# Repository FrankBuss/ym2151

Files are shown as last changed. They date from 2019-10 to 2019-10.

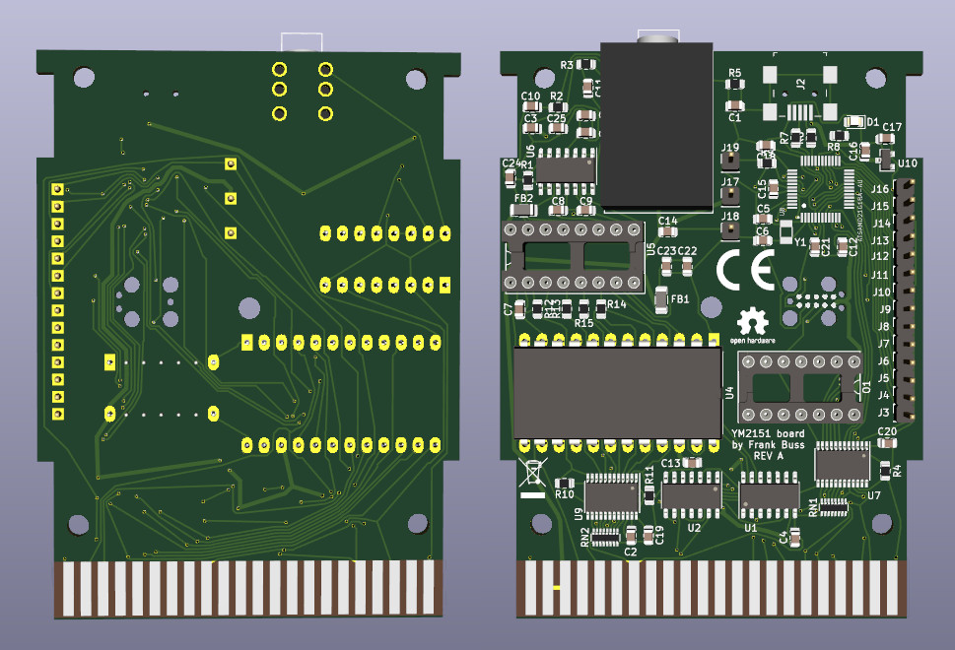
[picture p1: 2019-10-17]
KiCAD/board.jpg

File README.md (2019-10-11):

# YM2151 board for C64 and Arduino

## Original Z80 project
https://github.com/kuninet/Z80_YM2151

## C64 Sound Expander circuit diagram
https://www.c64-wiki.de/images/0/0f/Commodore_Sound_Expander_Schematic_SVG.svg

## Parts
TRS connector: https://www.tme.eu/en/details/acjs-nh35/jack-connectors/amphenol/

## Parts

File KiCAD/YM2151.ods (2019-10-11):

部品番号 | 仕様 | 数量 | 代替可能品 | Footprint
P1 | 1列x8 ピンヘッダ等 | 1 |  | Socket_Arduino_Uno:Socket_Strip_Arduino_1x08
P2 | 1列x6 ピンヘッダ等 | 1 |  | Socket_Arduino_Uno:Socket_Strip_Arduino_1x06
P4 | 1列x8 ピンヘッダ等 | 1 |  | Socket_Arduino_Uno:Socket_Strip_Arduino_1x08
P3 | 1列x10 ピンヘッダ等 | 1 |  | Socket_Arduino_Uno:Socket_Strip_Arduino_1x10
U1 | YM2151 | 1 | - | Housings_DIP:DIP-24_W15.24mm_Socket
U2 | YM3012 | 1 | - | Housings_DIP:DIP-16_W7.62mm_Socket
U3 | LMC6484 | 1 | LMC660CN等 4回路入 単一電源オペアンプ | Housings_DIP:DIP-14_W7.62mm_Socket
U4 | 74HC138 | 1 | 74HCT138 | Package_DIP:DIP-16_W7.62mm_Socket
C1 | 10uF | 1 | 電解コンデンサ | Capacitor_THT:CP_Radial_D5.0mm_P2.50mm
C2、C3 | 3300p | 2 | フィルム or 積層セラミックコンデンサ | Capacitor_THT:C_Disc_D4.3mm_W1.9mm_P5.00mm
C4、C5、C6、C10、C11 | 4.7u | 5 | 電解コンデンサ | Capacitor_THT:CP_Radial_D5.0mm_P2.50mm
C7、C8、C9 | 0.1u | 3 | 積層セラミックコンデンサ | Capacitor_THT:C_Disc_D3.0mm_W1.6mm_P2.50mm
R1、R2、R4 | 1kΩ | 3 | 1/4W カーボン抵抗器 | Resistors_THT:R_Axial_DIN0204_L3.6mm_D1.6mm_P7.62mm_Horizontal
R3 | 100kΩ | 1 | 1/4W カーボン抵抗器 | Resistor_THT:R_Axial_DIN0204_L3.6mm_D1.6mm_P7.62mm_Horizontal
R5 | 100Ω | 1 | 1/4W カーボン抵抗器 | Resistor_THT:R_Axial_DIN0204_L3.6mm_D1.6mm_P7.62mm_Horizontal
J1 | AJ-1780 | 1 | オーディオジャック | AJ-1780:AJ-1780
JP1 | 1列x3 ピンヘッダ | 1 |  | Connector_PinHeader_2.54mm:PinHeader_1x03_P2.54mm_Vertical
JP2 | 1列x3 ピンヘッダ | 1 |  | Connector_PinHeader_2.54mm:PinHeader_1x03_P2.54mm_Vertical
JP3 | 2列x8 ピンヘッダ | 1 |  | Connector_PinHeader_2.54mm:PinHeader_2x08_P2.54mm_Vertical
JP4 | 40pin L型ボックスヘッダ | 1 |  | Connector_PinHeader_2.54mm:PinHeader_2x20_P2.54mm_Horizontal
JP5 | 1列x3 ピンヘッダ | 1 |  | Connector_PinHeader_2.54mm:PinHeader_1x03_P2.54mm_Vertical
Q1 | 2SC1815 | 1 | 2SC1815同等品 | Package_TO_SOT_THT:TO-92_Inline_Wide
O1 | 3.579545MHz 水晶発振器 | 1 | 水晶発振器 (DIP14ピンサイズ) | Oscillator:Oscillator_DIP-14

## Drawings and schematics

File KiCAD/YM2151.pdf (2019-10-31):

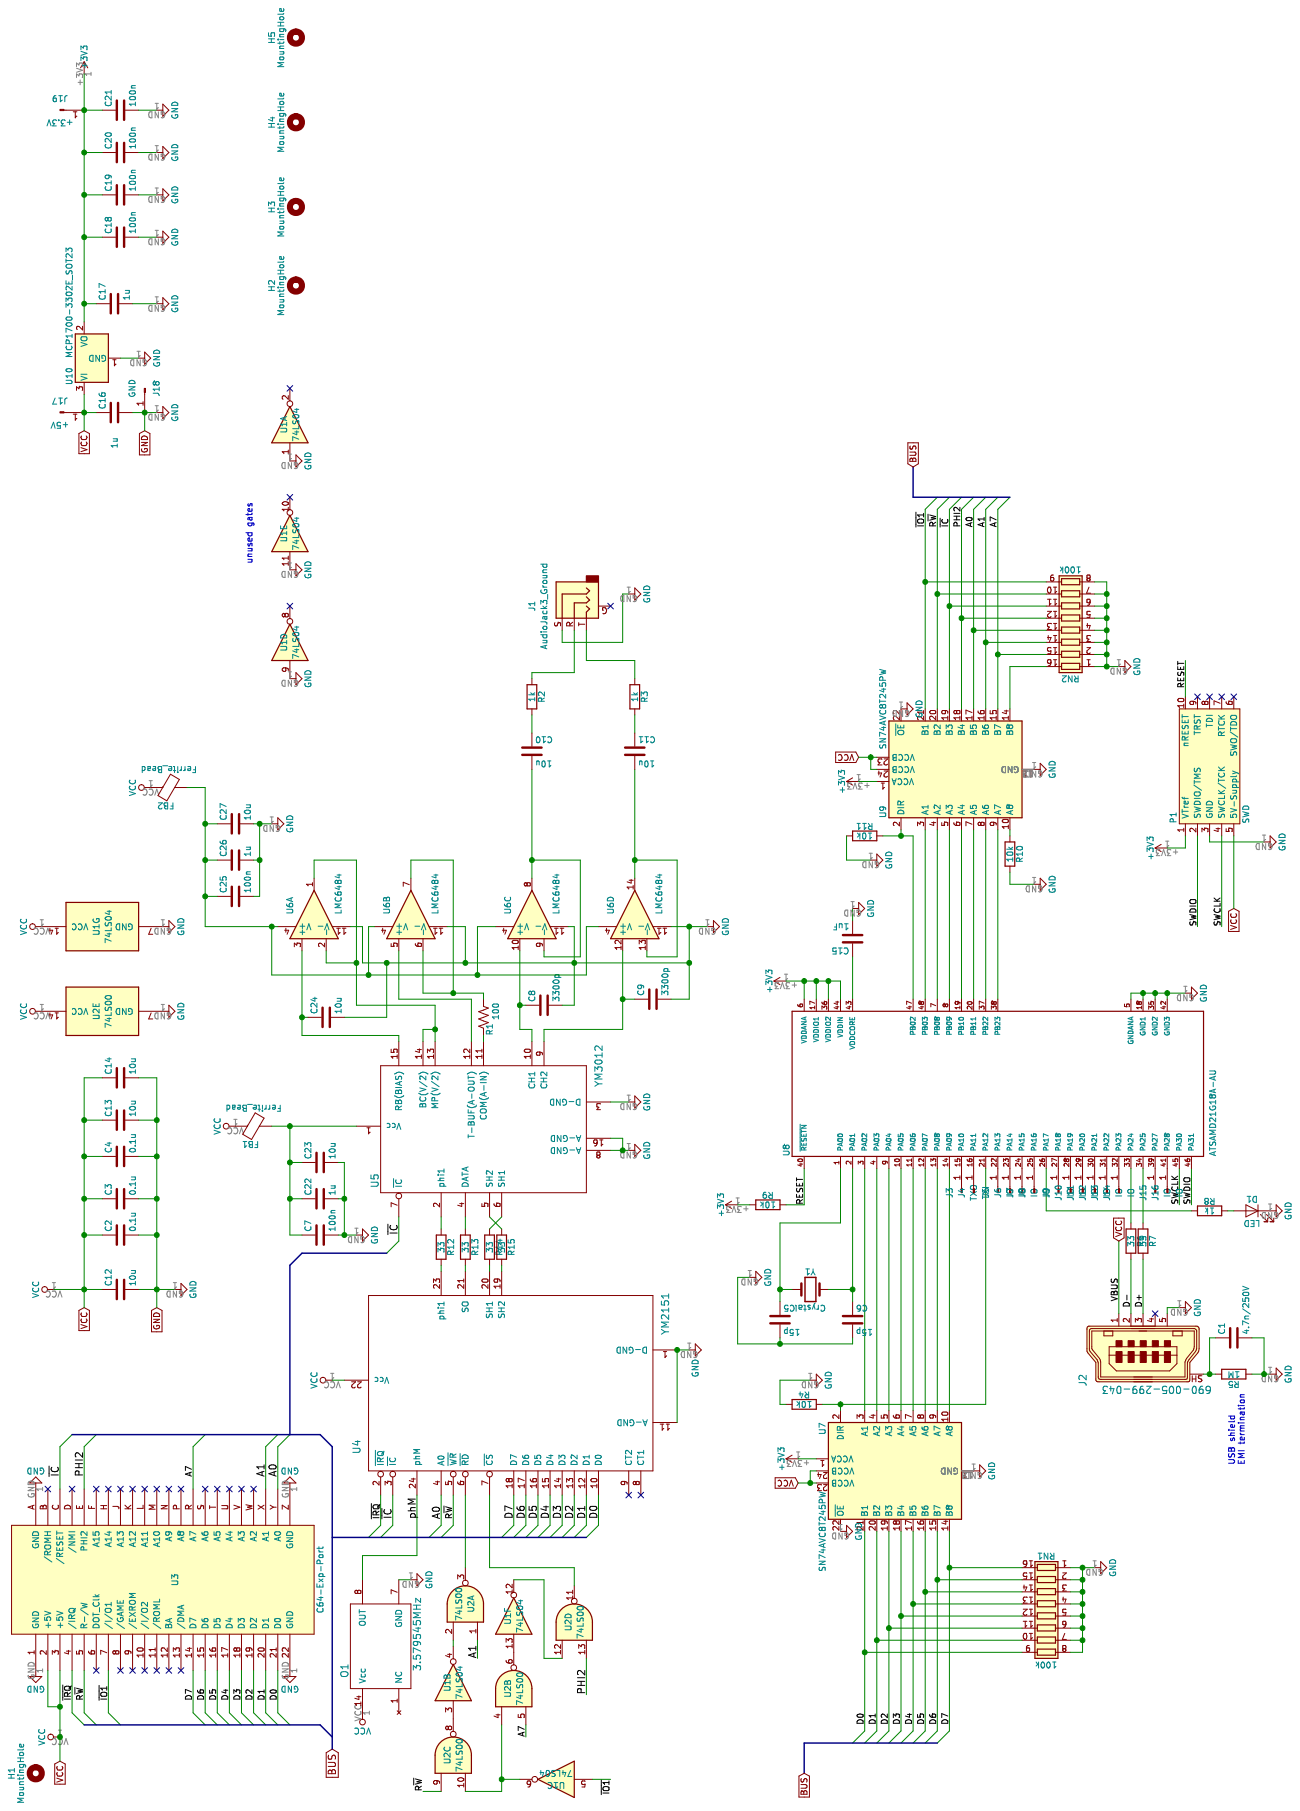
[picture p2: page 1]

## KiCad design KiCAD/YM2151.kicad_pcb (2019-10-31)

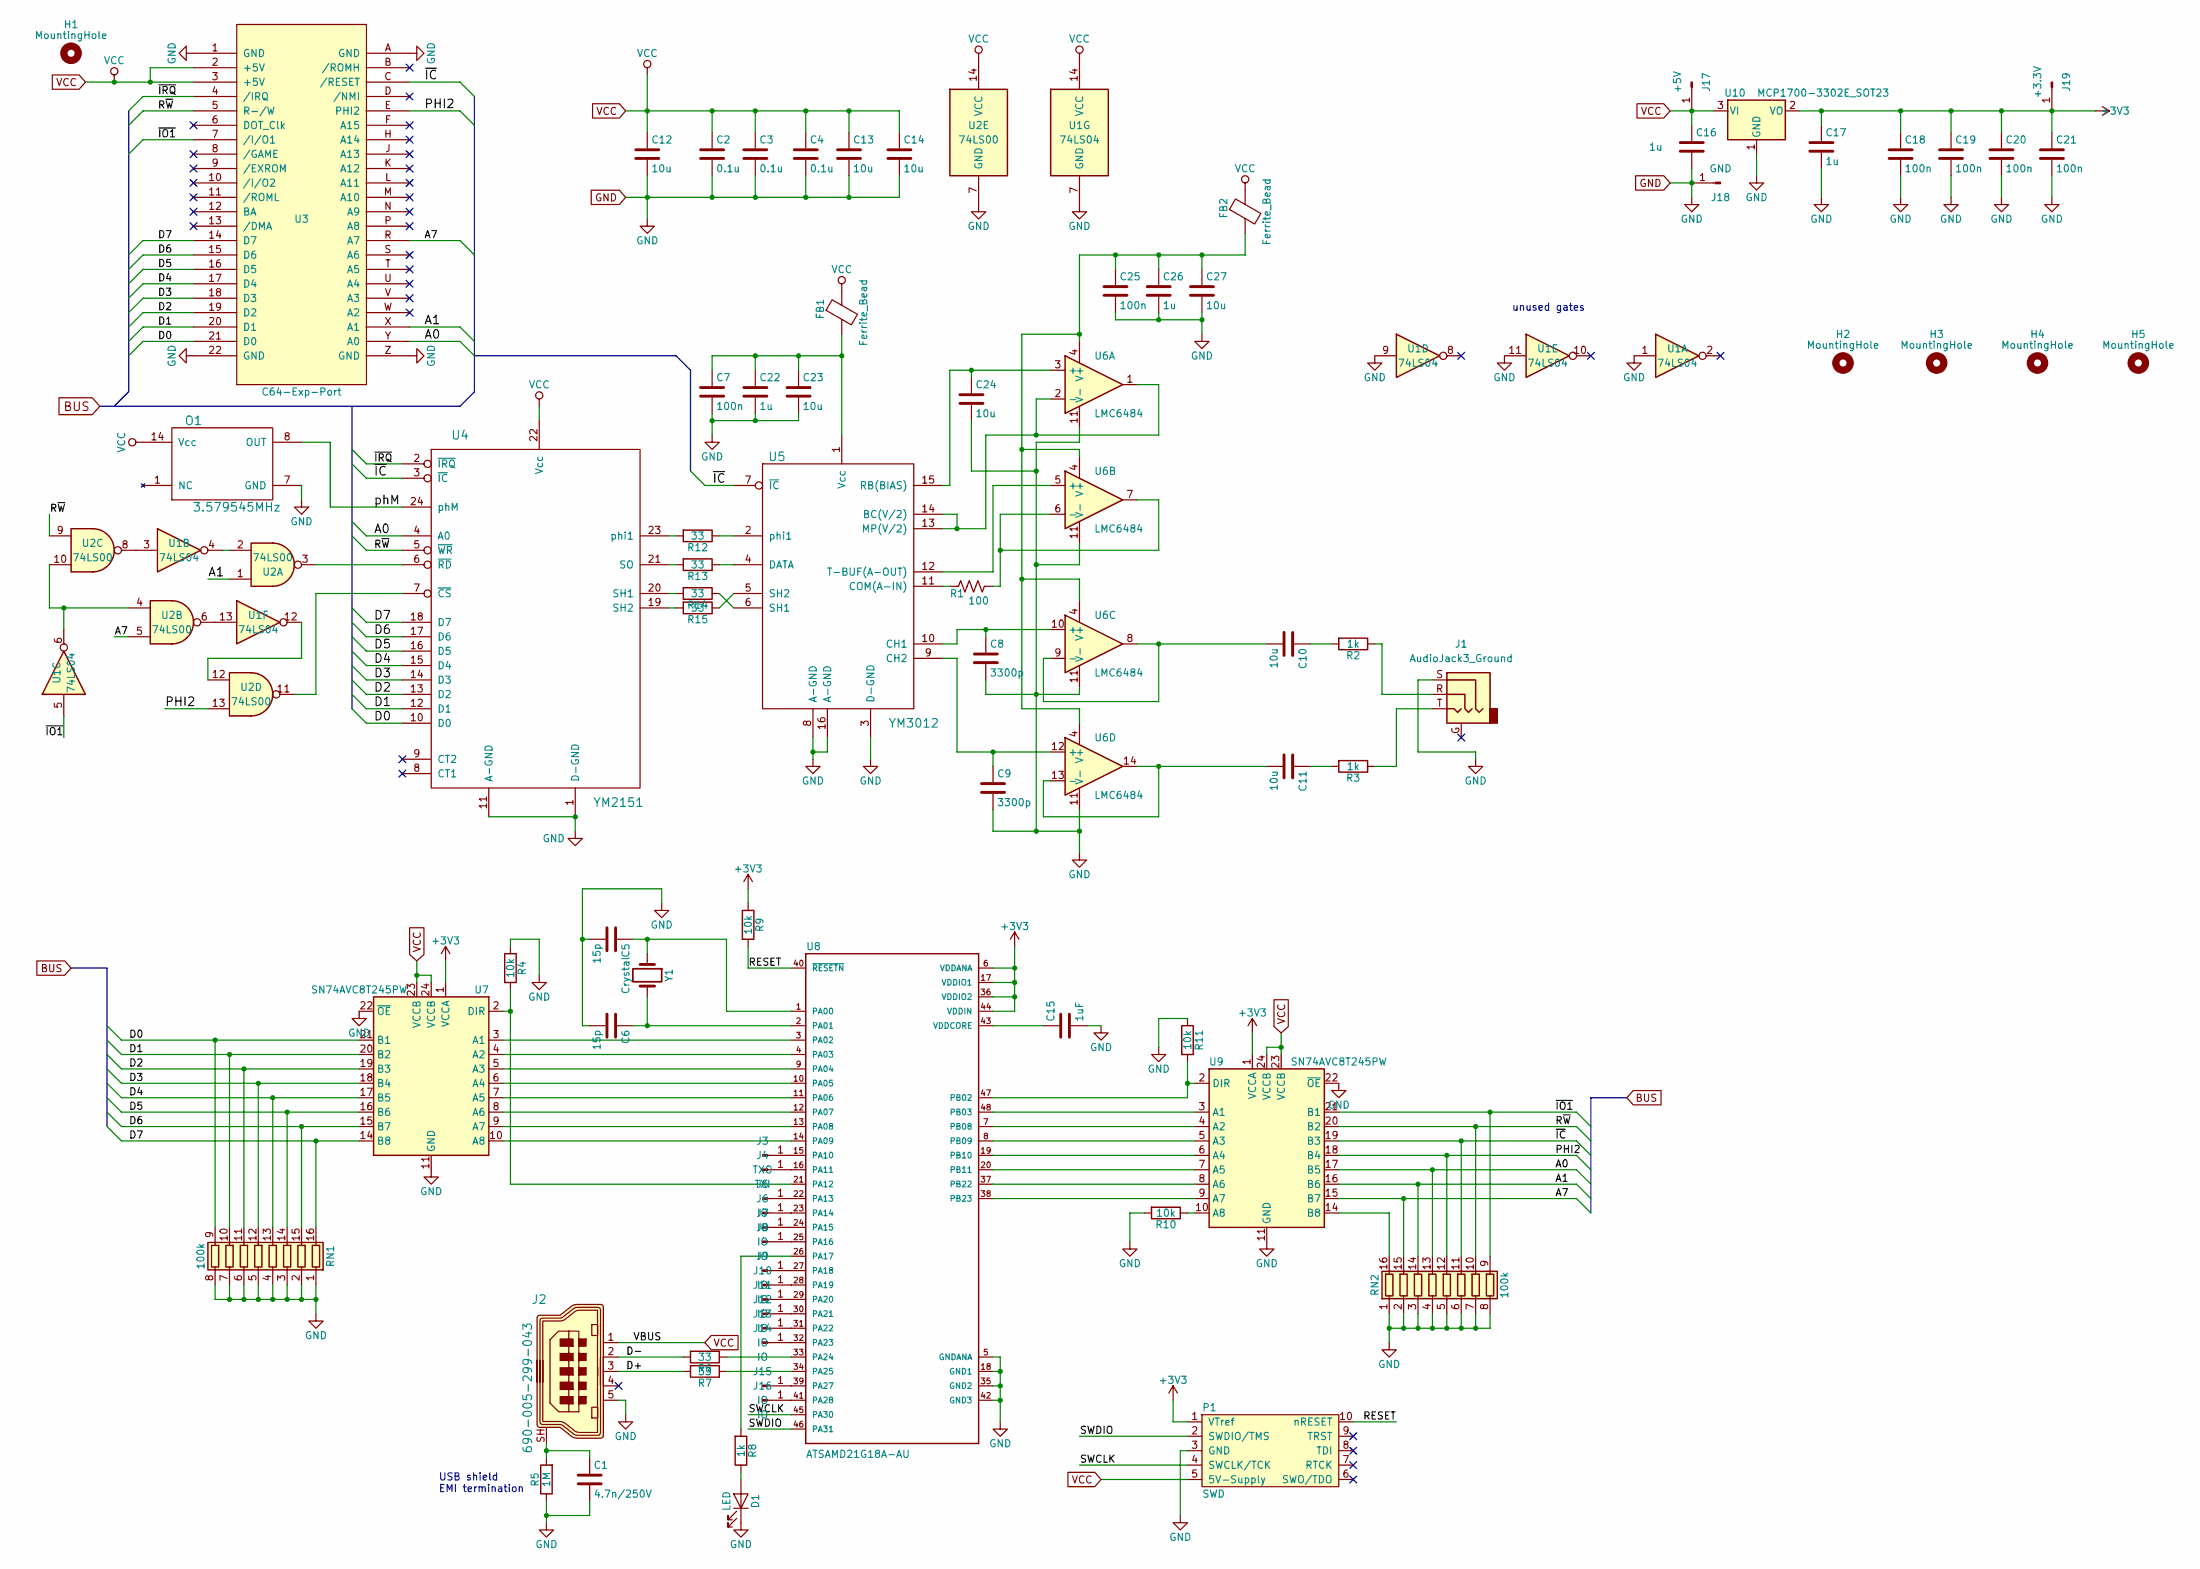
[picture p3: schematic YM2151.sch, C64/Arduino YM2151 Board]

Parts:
C1: 4.7n/250V; C_0805_2012Metric
C2, C3, C4: 0.1u; C_0805_2012Metric
C5, C6: 15p; C_0805_2012Metric
C7, C18, C19, C20, C21, C25: 100n; C_0805_2012Metric
C8, C9: 3300p; C_0805_2012Metric
C10, C11, C12, C13, C14, C23, C24, C27: 10u; C_0805_2012Metric
C15: 1uF; C_0805_2012Metric
C16, C17, C22, C26: 1u; C_0805_2012Metric
D1: LED; LED_0805_2012Metric
FB1, FB2: Ferrite_Bead; L_1206_3216Metric
H1, H2, H3, H4, H5: MountingHole; MountingHole_3.2mm_M3
J1: AudioJack3_Ground; trs
J2: 690-005-299-043; USB_Mini_B_Female_690-005-299-043; MPN 690-005-299-043; Digi-Key_PN 151-1206-1-ND
J3: TXO; PinHeader_1x01_P2.54mm_Vertical
J4: TXI; PinHeader_1x01_P2.54mm_Vertical
J5, J6, J7, J8, J9, J10, J11, J12, J13, J14, J15, J16: IO; PinHeader_1x01_P2.54mm_Vertical
J17: +5V; PinHeader_1x01_P2.54mm_Vertical
J18: GND; PinHeader_1x01_P2.54mm_Vertical
J19: +3.3V; PinHeader_1x01_P2.54mm_Vertical
O1: 3.579545MHz; DIP-14_W7.62mm_Socket_LongPads
P1: SWD; swd
R1: 100; R_0805_2012Metric
R2, R3, R8: 1k; R_0805_2012Metric
R4, R9, R10, R11: 10k; R_0805_2012Metric
R5: 1M; R_0805_2012Metric
R6, R7, R12, R13, R14, R15: 33; R_0805_2012Metric
RN1, RN2: 100k; R_Array_Convex_8x0602
U1: 74LS04; SOIC-14_3.9x8.7mm_P1.27mm
U2: 74LS00; SOIC-14_3.9x8.7mm_P1.27mm
U3: C64-Exp-Port; C64-Cart
U4: YM2151; DIP-24_W15.24mm_LongPads
U5: YM3012; DIP-16_W7.62mm_Socket_LongPads
U6: LMC6484; SOIC-14_3.9x8.7mm_P1.27mm
U7, U9: SN74AVC8T245PW; TSSOP-24_4.4x7.8mm_P0.65mm
U8: ATSAMD21G18A-AU; QFP50P900X900X120-48N
U10: MCP1700-3302E_SOT23; SOT-23
Y1: Crystal; Crystal_SMD_3215-2Pin_3.2x1.5mm

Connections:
+3V3: C17.1, C18.1, C19.1, C20.1, C21.1, J19.1, P1.1 (VTref), R9.1, U7.1 (VCCA), U8.6 (VDDANA), U8.17 (VDDIO1), U8.36 (VDDIO2), U8.44 (VDDIN), U9.1 (VCCA), U10.2 (VO)
/A0: RN2.13 (R4.2), U3.Y (A0), U4.4 (A0), U9.17 (B5)
/A1: RN2.14 (R3.2), U2.1, U3.X (A1), U9.16 (B6)
/A7: RN2.15 (R2.2), U2.5, U3.R (A7), U9.15 (B7)
/D0: RN1.9 (R8.2), U3.21 (D0), U4.10 (D0), U7.21 (B1)
/D1: RN1.10 (R7.2), U3.20 (D1), U4.12 (D1), U7.20 (B2)
/D2: RN1.11 (R6.2), U3.19 (D2), U4.13 (D2), U7.19 (B3)
/D3: RN1.12 (R5.2), U3.18 (D3), U4.14 (D3), U7.18 (B4)
/D4: RN1.13 (R4.2), U3.17 (D4), U4.15 (D4), U7.17 (B5)
/D5: RN1.14 (R3.2), U3.16 (D5), U4.16 (D5), U7.16 (B6)
/D6: RN1.15 (R2.2), U3.15 (D6), U4.17 (D6), U7.15 (B7)
/D7: RN1.16 (R1.2), U3.14 (D7), U4.18 (D7), U7.14 (B8)
/D+: J2.3, R7.2
/D-: J2.2, R6.2
/PHI2: RN2.12 (R5.2), U2.13, U3.E (PHI2), U9.18 (B4)
/RESET: P1.10 (nRESET), R9.2, U8.40 (~RESETN~)
/R~W: RN2.10 (R7.2), U2.9, U3.5 (R-/W), U4.5 (~WR), U9.20 (B2)
/SWCLK: P1.4 (SWCLK/TCK), U8.45 (PA30)
/SWDIO: P1.2 (SWDIO/TMS), U8.46 (PA31)
/phM: O1.8 (OUT), U4.24 (phM)
/~IC: RN2.11 (R6.2), U3.C (/RESET), U4.3 (~IC), U5.7 (~IC), U9.19 (B3)
/~IO1: RN2.9 (R8.2), U1.5, U3.7 (/I/O1), U9.21 (B1)
/~IRQ: U3.4 (/IRQ), U4.2 (~IRQ)
GND: C1.2, C2.2, C3.2, C4.2, C5.2, C6.2, C7.2, C8.2, C9.2, C12.2, C13.2, C14.2, C15.2, C16.2, C17.2, C18.2, C19.2, C20.2, C21.2, C22.2, C23.2, C24.2, C25.2, C26.2, C27.2, D1.1 (K), J1.S, J2.5, J18.1, O1.7 (GND), P1.3 (GND), R4.1, R5.1, R10.2, R11.1, RN1.1 (R1.1), RN1.2 (R2.1), RN1.3 (R3.1), RN1.4 (R4.1), RN1.5 (R5.1), RN1.6 (R6.1), RN1.7 (R7.1), RN1.8 (R8.1), RN2.1 (R1.1), RN2.2 (R2.1), RN2.3 (R3.1), RN2.4 (R4.1), RN2.5 (R5.1), RN2.6 (R6.1), RN2.7 (R7.1), RN2.8 (R8.1), U1.1, U1.7 (GND), U1.9, U1.11, U2.7 (GND), U3.1 (GND), U3.22 (GND), U3.A (GND), U3.Z (GND), U4.1 (D-GND), U4.11 (A-GND), U5.3 (D-GND), U5.8 (A-GND), U5.16 (A-GND), U6.11 (V-), U7.11 (GND), U7.12 (GND), U7.13 (GND), U7.22 (~OE), U8.5 (GNDANA), U8.18 (GND1), U8.35 (GND2), U8.42 (GND3), U9.11 (GND), U9.12 (GND), U9.13 (GND), U9.22 (~OE), U10.1 (GND)
unnamed: C1.1, J2.SH, R5.2
unnamed: C5.1, U8.1 (PA00), Y1.1
unnamed: C6.1, U8.2 (PA01), Y1.2
unnamed: C8.1, U5.10 (CH1), U6.10 (+)
unnamed: C9.1, U5.9 (CH2), U6.12 (+)
unnamed: C10.1, R2.2
unnamed: C10.2, U6.8, U6.9 (-)
unnamed: C11.1, R3.2
unnamed: C11.2, U6.13 (-), U6.14
unnamed: C15.1, U8.43 (VDDCORE)
unnamed: C7.1, C22.1, C23.1, FB1.2, U5.1 (Vcc)
unnamed: C24.1, U5.15 (RB(BIAS)), U6.3 (+)
unnamed: C25.1, C26.1, C27.1, FB2.2, U6.4 (V+)
unnamed: D1.2 (A), R8.1
unnamed: J1.R, R2.1
unnamed: J1.T, R3.1
unnamed: J3.1, U8.15 (PA10)
unnamed: J4.1, U8.16 (PA11)
unnamed: J5.1, U8.22 (PA13)
unnamed: J6.1, U8.23 (PA14)
unnamed: J7.1, U8.24 (PA15)
unnamed: J8.1, U8.25 (PA16)
unnamed: J9.1, U8.27 (PA18)
unnamed: J10.1, U8.28 (PA19)
unnamed: J11.1, U8.29 (PA20)
unnamed: J12.1, U8.30 (PA21)
unnamed: J13.1, U8.31 (PA22)
unnamed: J14.1, U8.32 (PA23)
unnamed: J15.1, U8.39 (PA27)
unnamed: J16.1, U8.41 (PA28)
unnamed: R1.1, U6.6 (-), U6.7
unnamed: R1.2, U5.11 (COM(A-IN))
unnamed: R4.2, U7.2 (DIR), U8.21 (PA12)
unnamed: R6.1, U8.33 (PA24)
unnamed: R7.1, U8.34 (PA25)
unnamed: R8.2, U8.26 (PA17)
unnamed: R10.1, U9.10 (A8)
unnamed: R11.2, U8.47 (PB02), U9.2 (DIR)
unnamed: R12.1, U5.2 (phi1)
unnamed: R12.2, U4.23 (phi1)
unnamed: R13.1, U5.4 (DATA)
unnamed: R13.2, U4.21 (SO)
unnamed: R14.1, U5.6 (SH1)
unnamed: R14.2, U4.20 (SH1)
unnamed: R15.1, U5.5 (SH2)
unnamed: R15.2, U4.19 (SH2)
unnamed: RN2.16 (R1.2), U9.14 (B8)
unnamed: U1.3, U2.8
unnamed: U1.4, U2.2
unnamed: U1.6, U2.4, U2.10
unnamed: U1.12, U2.12
unnamed: U1.13, U2.6
unnamed: U2.3, U4.6 (~RD)
unnamed: U2.11, U4.7 (~CS)
unnamed: U5.12 (T-BUF(A-OUT)), U6.5 (+)
unnamed: U5.13 (MP(V/2)), U5.14 (BC(V/2)), U6.1, U6.2 (-)
unnamed: U7.3 (A1), U8.3 (PA02)
unnamed: U7.4 (A2), U8.4 (PA03)
unnamed: U7.5 (A3), U8.9 (PA04)
unnamed: U7.6 (A4), U8.10 (PA05)
unnamed: U7.7 (A5), U8.11 (PA06)
unnamed: U7.8 (A6), U8.12 (PA07)
unnamed: U7.9 (A7), U8.13 (PA08)
unnamed: U7.10 (A8), U8.14 (PA09)
unnamed: U8.7 (PB08), U9.4 (A2)
unnamed: U8.8 (PB09), U9.5 (A3)
unnamed: U8.19 (PB10), U9.6 (A4)
unnamed: U8.20 (PB11), U9.7 (A5)
unnamed: U8.37 (PB22), U9.8 (A6)
unnamed: U8.38 (PB23), U9.9 (A7)
unnamed: U8.48 (PB03), U9.3 (A1)
VCC: C2.1, C3.1, C4.1, C12.1, C13.1, C14.1, C16.1, FB1.1, FB2.1, J2.1, J17.1, O1.14 (Vcc), P1.5 (5V-Supply), U1.14 (VCC), U2.14 (VCC), U3.2 (+5V), U3.3 (+5V), U4.22 (Vcc), U7.23 (VCCB), U7.24 (VCCB), U9.23 (VCCB), U9.24 (VCCB), U10.3 (VI)

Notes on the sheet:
unused gates
USB shield EMI termination

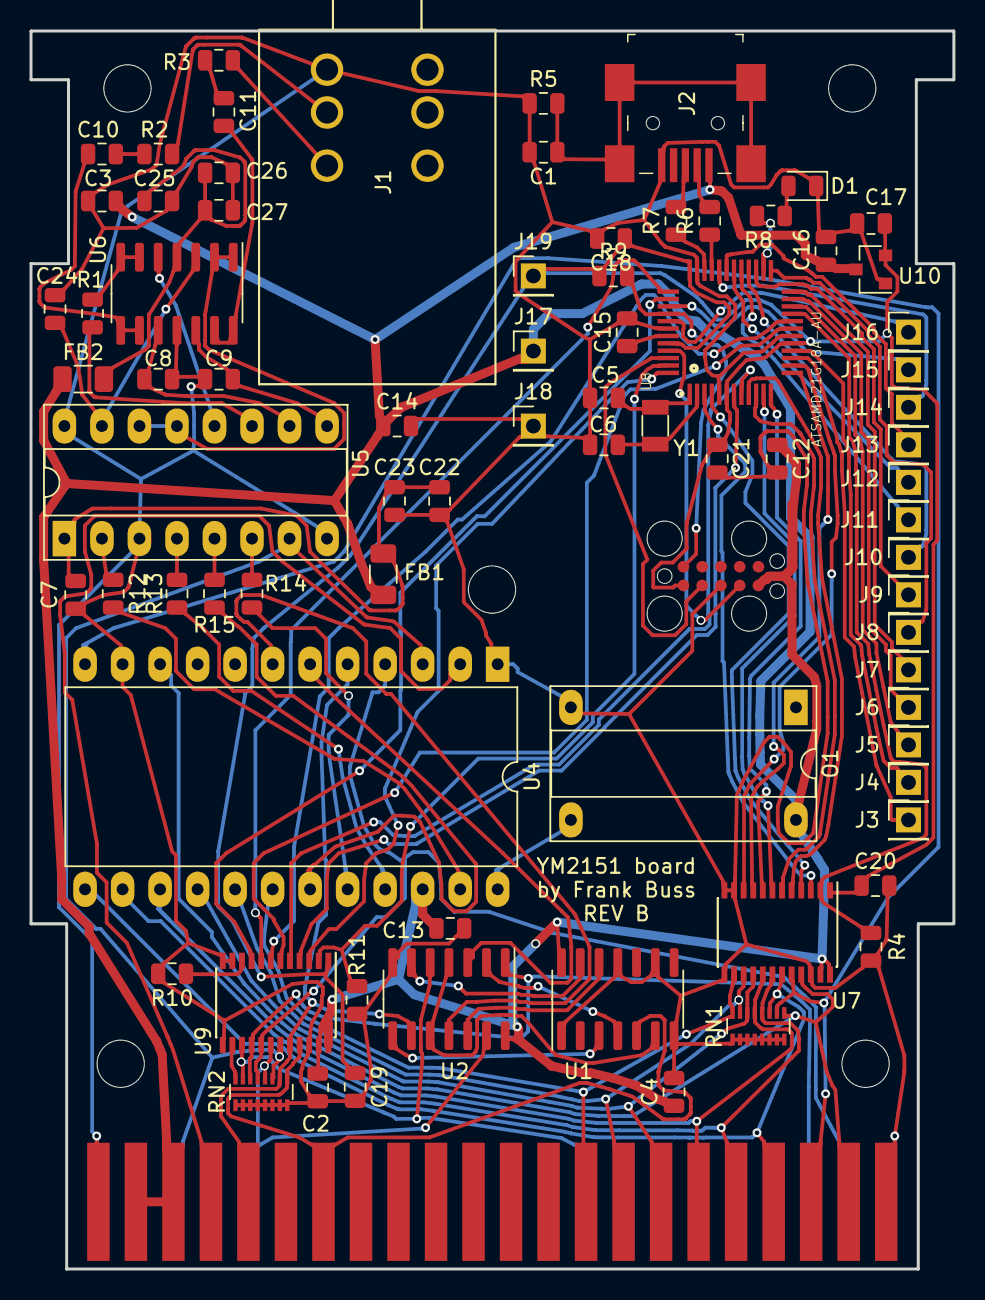
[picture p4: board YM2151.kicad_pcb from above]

Board: 2 copper layers, 62.5 x 83.8 mm, 84 parts (0 on the bottom side), 96 nets.

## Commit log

2019-10-15 microcontroller added
    [YM2151.kicad_pcb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]
2019-10-17 board routed
    [YM2151.dsn, YM2151.kicad_pcb, YM2151.sch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]
2019-10-17 final REV A version with gerber files
    [YM2151.kicad_pcb]
2019-10-17 KiCad rendering of the board updated
2019-10-24 HTML BOM
2019-10-31 REV B
    [YM2151.csv, YM2151.kicad_pcb, YM2151.sch]
